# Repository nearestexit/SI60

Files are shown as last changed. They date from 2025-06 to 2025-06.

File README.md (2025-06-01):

# SI60

[QMK](https://github.com/qmk/qmk_firmware) Compatible Open Hardware GH60-compatible USB-C PCBs designed for use with [Hi-Tek 725 "Space Invaders" Switches](https://wiki.vintkeys.ca/NMB/Switches) in a variety of layouts, including variants of NMB keyboards with and without stepped caps.

## Overview
The main features of this project are:
 - Support for nearly every possible 60% set of caps you could use, including all NMB RT101+ keyboards in ANSI and ISO, with stepped and unstepped caps, Erase-Eaze, and ADDS/Televideo ANSI layouts.
 - Future-proof STM32F072CBT6 MCU
 - Design optimized for hand-soldering, with no parts smaller than 0603, and an MCU that does not require an external crystal
 - Compatibility with the original GH60 footprint
 - Compatibility (theoretically) with the Bakeneko60 footprint
 
 **Important: The distance from the plate to PCB on Space Invaders switches is larger than that for MX switches. You must do your own research to confirm compatibility with whatever case you choose.
 Tray-mount cases are likely to work okay, but for top-mount keyboards, the pins may short out on the bottom of the case.
 I will update this page when compatibility with a certain case is confirmed, but other than that, I cannot answer questions like "is X keyboard with this PCB"**

Production files are included for production at [JLCPCB](https://jlcpcb.com/).

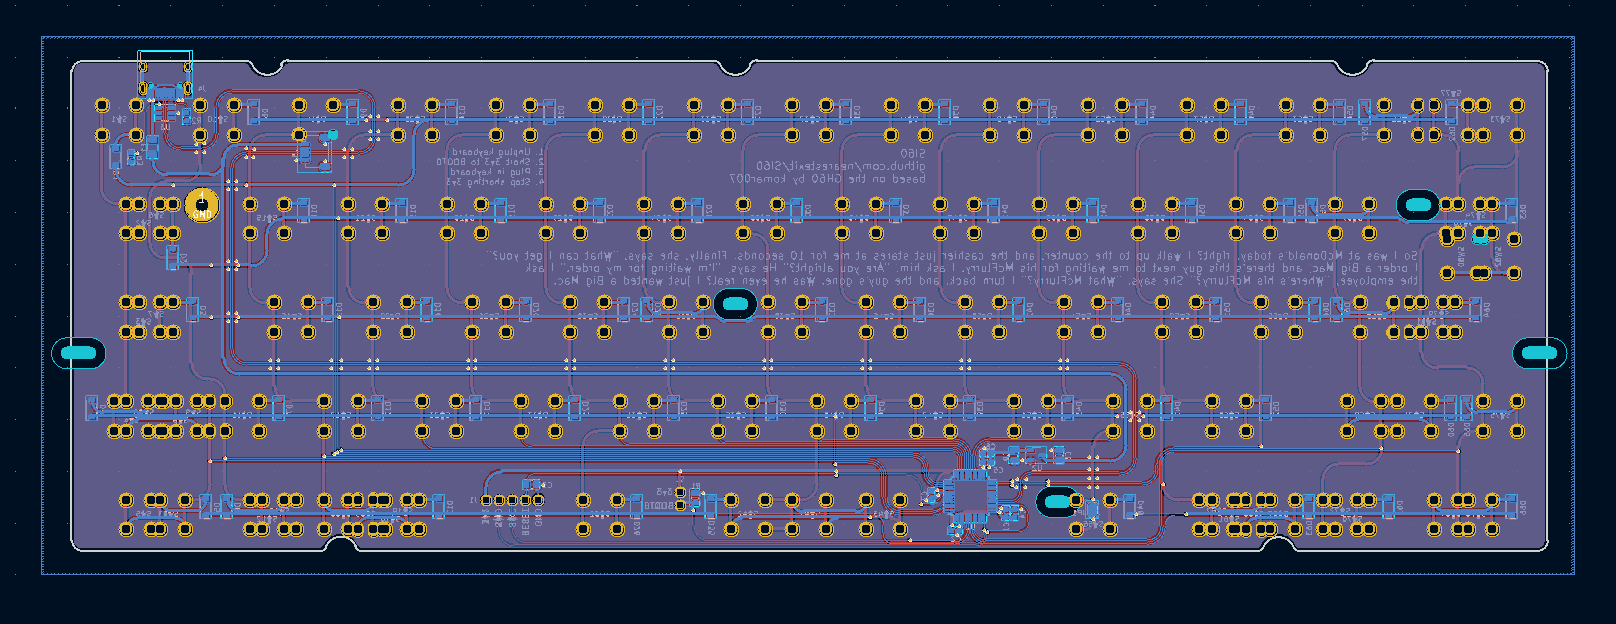
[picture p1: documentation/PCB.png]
Overview


## Supported layouts
 - Stepped and unstepped ISO, ANSI, BAE
 - Televideo ANSI bottom row
 - ADDS ANSI bottom row

**Please note: compatibility for the more obscure layouts is untested.**

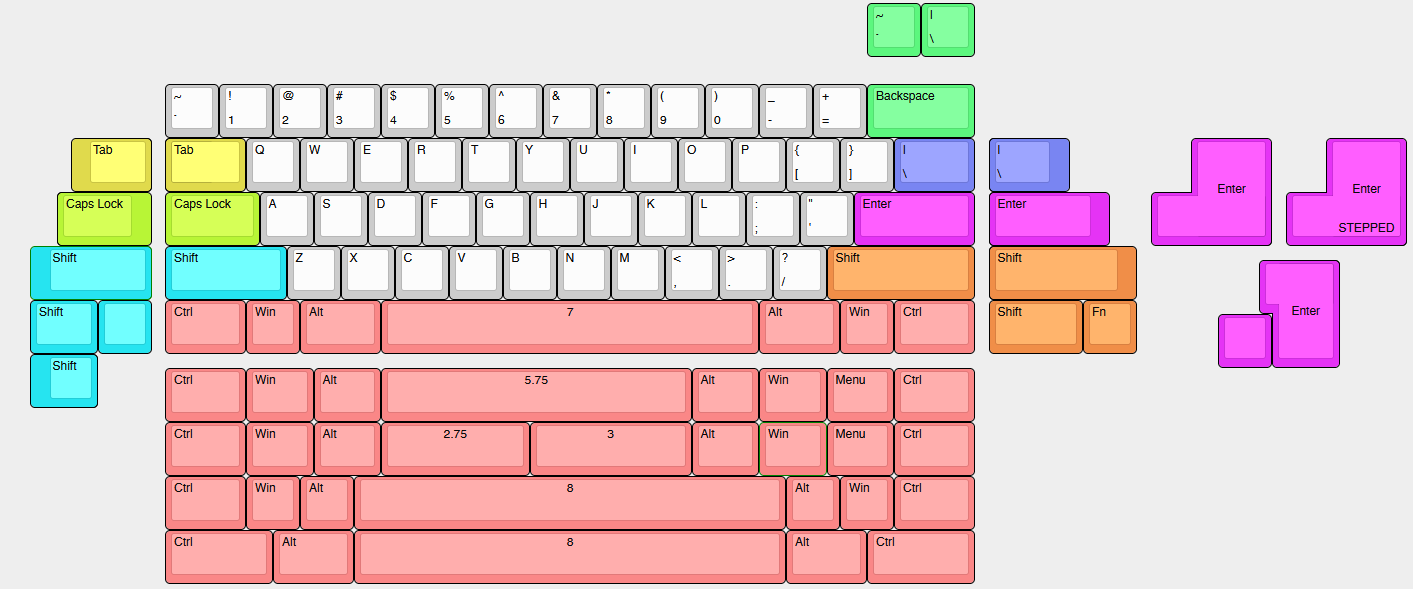
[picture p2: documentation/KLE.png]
KLE


## Configuration options
 - To fit in a GH60 case, the JST ought to be depopulated.
 - To fit in a Bakeneko60 case, the USB-C ought to be depopulated.

## JLCPCB Ordering Information
1. On jlcpcb.com, click "order now" and "add gerber file"
2. Navigate to the directory with the gerber.zip - for example, SI60\jlcpcb\production_files
3. Wait for the gerber to upload.
4. Select the number of PCBs you wish to build.
5. Make sure PCB thickness is set to 1.6mm.
6. Make sure Via covering is set to "tented".
7. Make sure Min via hole size/diameter is set to "0.3mm"
8. Turn the "PCB Assembly" option on
9. Make sure PCBA type is set to "Economic"
10. For "Assembly side", if you are ordering the daughterboard select "top side", otherwise select "bottom side"
11. Click "next", and then "next" again
12. Click "Add BOM File" and select the BOM csv - for example, BOM-SI60.csv
13. Click "Add CPL File" and select the CPL csv - for example, CPL-SI60.csv
14. Click "Process BOM and CPL"
15. Make sure all parts are in stock - if any are not in stock, you will need to find replacements
16. Decide whether you want the USB-C soldered or the JST soldered, and uncheck the box next to the one you don't want
17. **IMPORTANT:** Click "Bottom" to view the bottom side of the PCB, and begin inspecting the component placements. You **WILL** need to correct some component rotations. If you are not sure at this step, do not continue!
18. Click "next" and finish checking out.

## Firmware
- [Vial-QMK](https://get.vial.today/) .uf2 files are provided in the firmware folder.
- To put the keyboard into bootloader mode to flash the firmware:
1. Open QMK toolbox, select the firmware file, and check the box for "auto flash"
2. Unplug the USB cable
3. Short the 3v3 and BOOT0 pins with a pair of tweezers
4. Plug the USB cable in
5. Stop shorting the BOOT pins.
- The STM32 will then be recognized by QMK toolbox, and it will load the firmware.
- You may need to reconnect the keyboard after flashing.
- Once you have flashed the firmware, you can change the keymap from [vial.rocks](https://vial.rocks)

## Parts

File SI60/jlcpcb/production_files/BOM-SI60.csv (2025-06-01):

Comment | Designator | Footprint | LCSC | Quantity
100n | C1,C2,C5,C7 | C_0603_1608Metric | C14663 | 4
Conn_01x04_MountingPin | J3 | JST_SH_SM04B-SRSS-TB_1x04-1MP_P1.00mm_Horizontal | C160404 | 1
USB_C_Receptacle_USB2.0 | J4 | USB_C_Receptacle_HRO_TYPE-C-31-M-12 | C165948 | 1
10k | R1 | R_0805_2012Metric | C17414 | 1
4.7u | C4,C6 | C_0603_1608Metric | C19666 | 2
5.1k | R2,R3 | R_0603_1608Metric | C23186 | 2
1u | C3,C8,C9 | C_0805_2012Metric | C28323 | 3
XC6206PxxxMR | U2 | SOT-23-3 | C5446 | 1
500mA | F1 | Fuse_1206_3216Metric | C70076 | 1
D_Small | D1,D10,D11,D12,D13,D14,D15,D16,D17,D18,D19,D2,D20,D21,D22,D23,D24,D25,D26,D27,D28,D29,D3,D30,D31,D32,D33,D34,D35,D36,D37,D38,D39,D4,D40,D41,D42,D43,D44,D45,D46,D47,D48,D49,D5,D50,D51,D52,D53,D54,D55,D56,D57,D58,D59,D6,D60,D61,D62,D63,D64,D65,D66,D7,D8,D9 | D_SOD-123 | C81598 | 66
STM32F072CBTx | U1 | LQFP-48_7x7mm_P0.5mm | C81720 | 1
SRV05-4 | U3 | SOT-23-6-routable | C85364 | 1

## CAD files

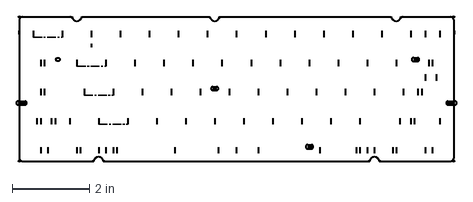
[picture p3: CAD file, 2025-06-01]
SI60/drawings/Drawing - PCB Layout.dxf
11.4 x 3.76 in

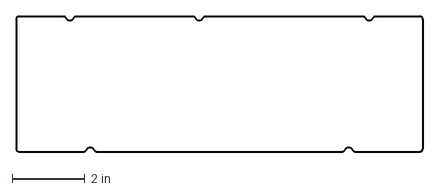
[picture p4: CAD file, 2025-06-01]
SI60/drawings/Drawing - PCB Edge Cuts.dxf
11.2 x 3.72 in

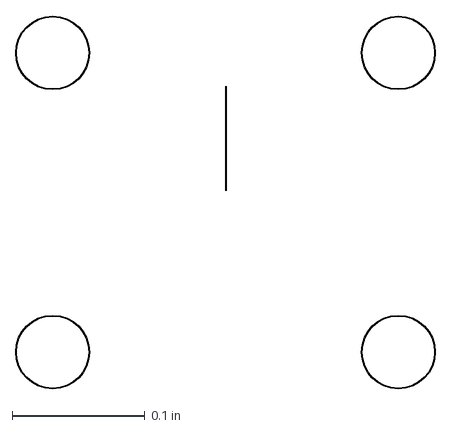
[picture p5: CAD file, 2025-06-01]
SI60/drawings/Footprint.dxf
0.315 x 0.28 in

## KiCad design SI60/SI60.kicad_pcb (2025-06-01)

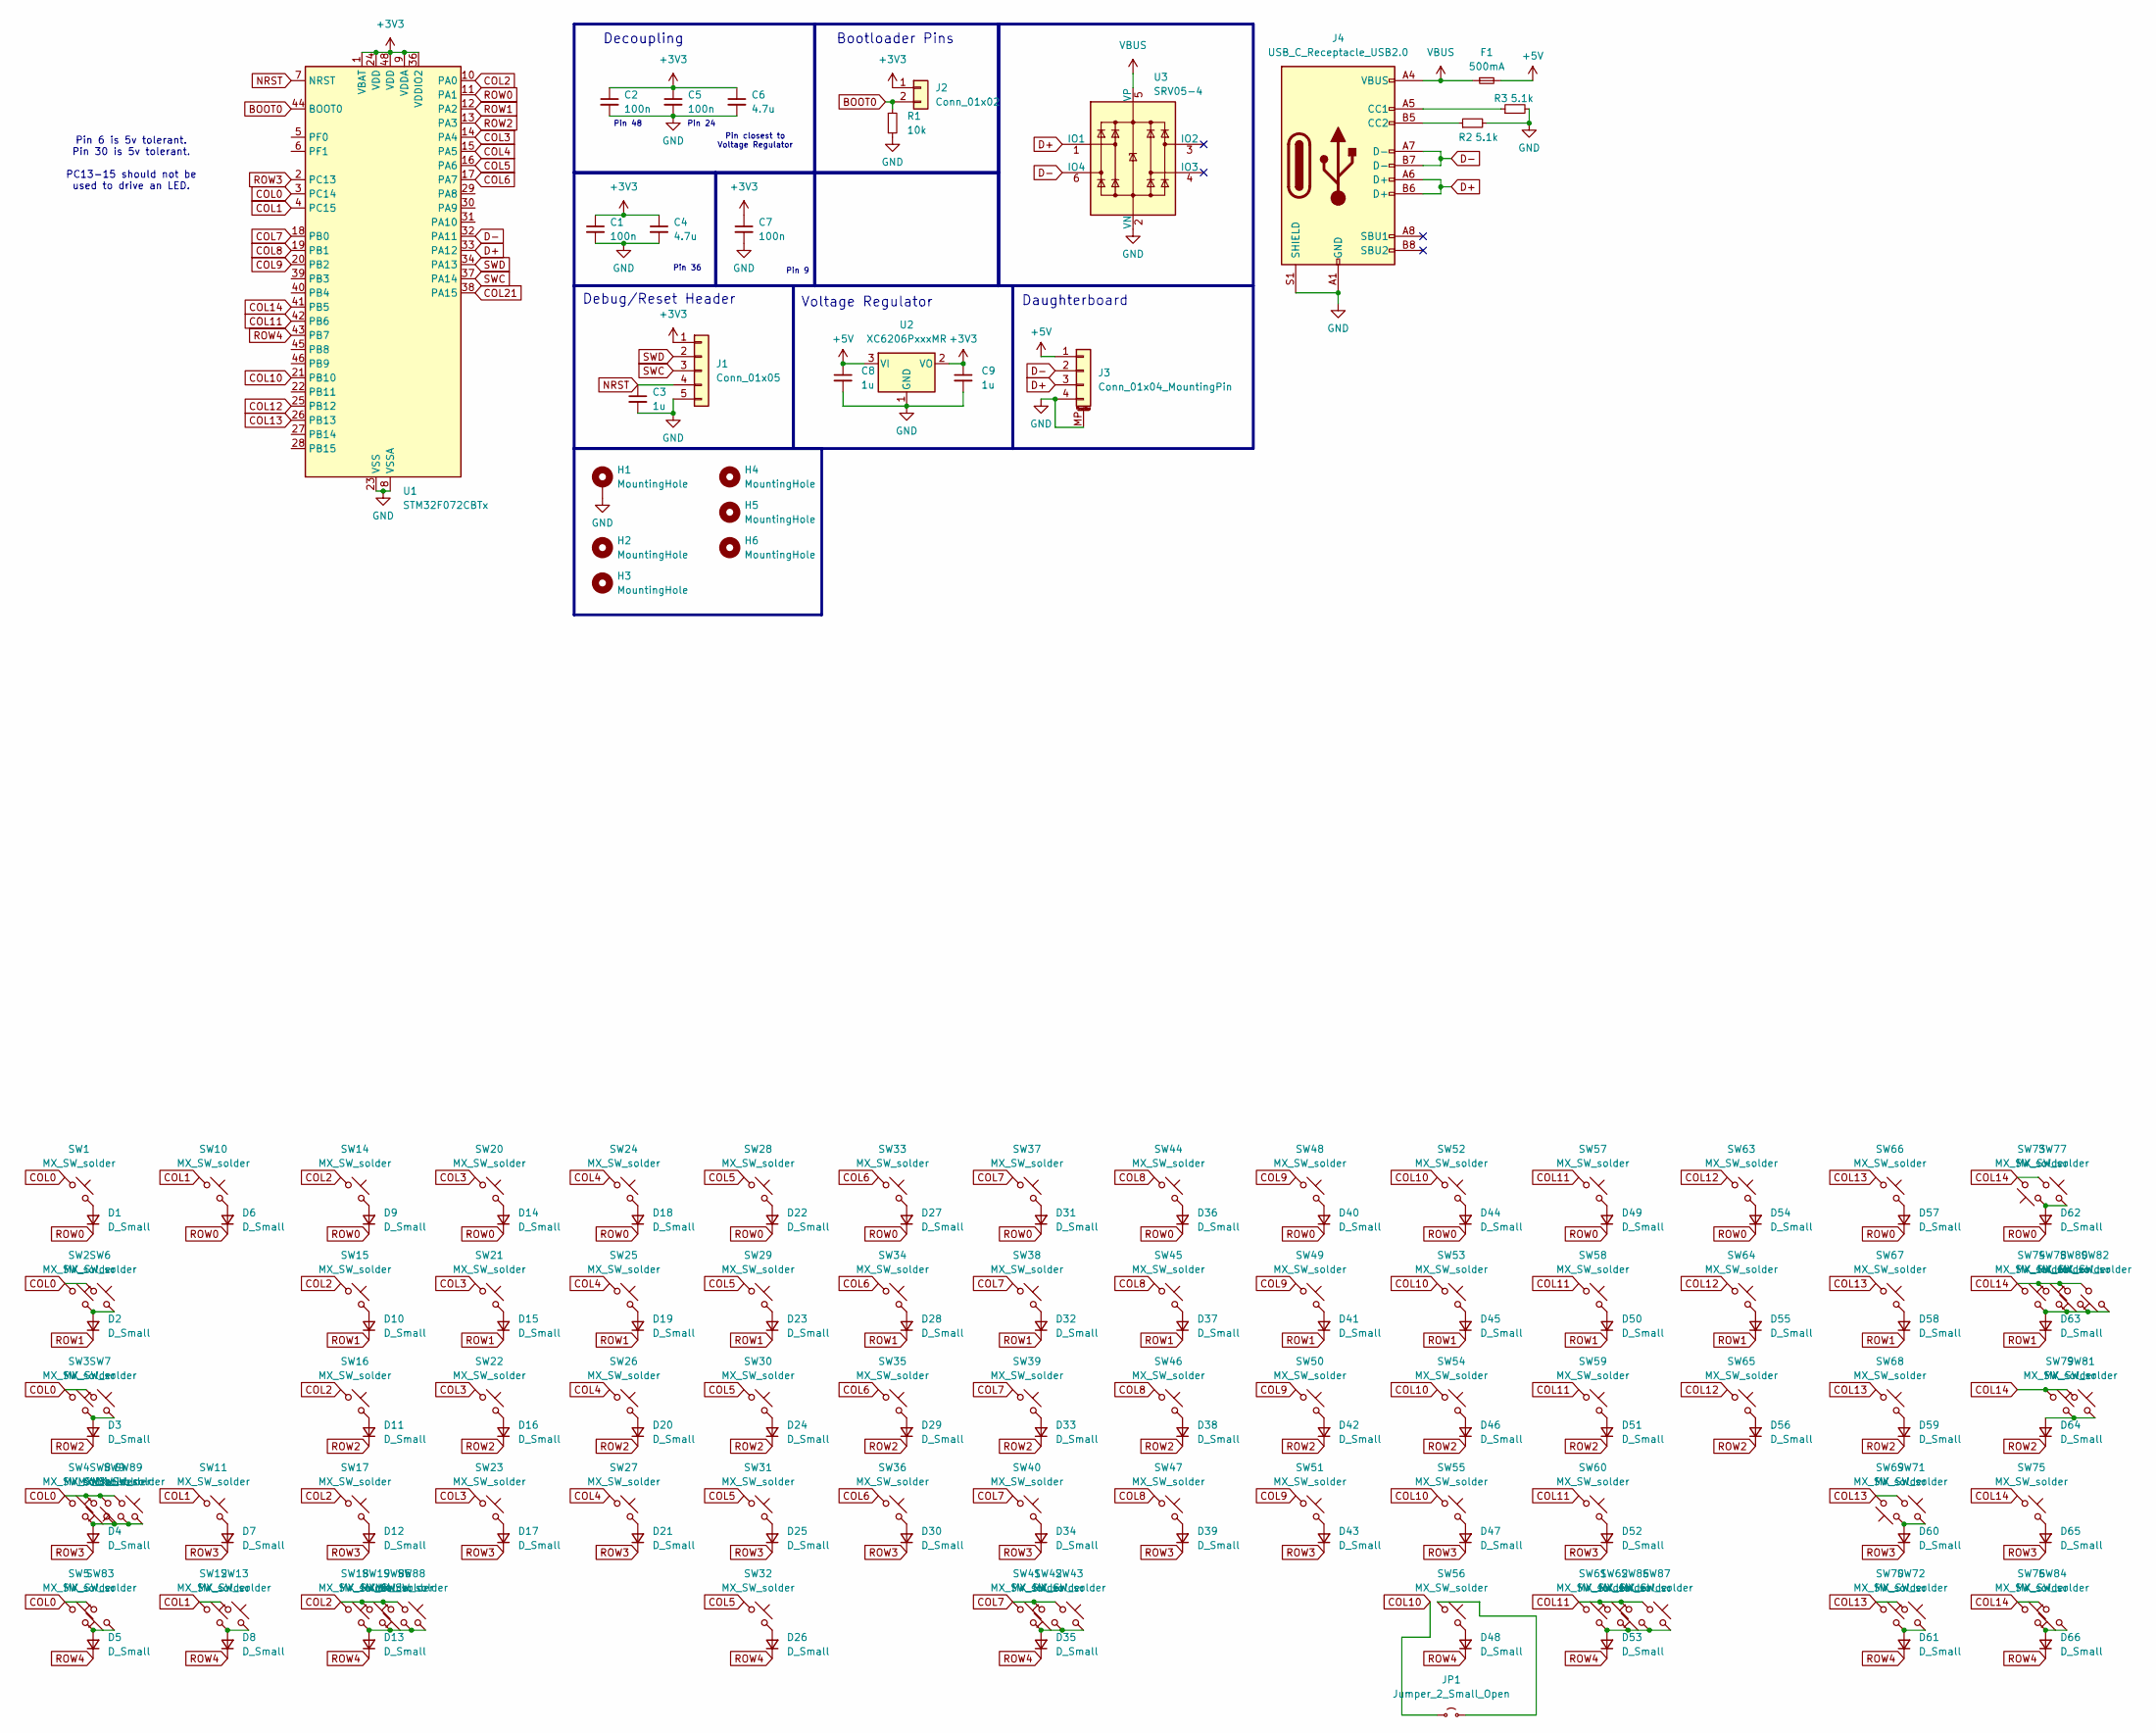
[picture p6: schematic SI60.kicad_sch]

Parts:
C1, C2, C5, C7: 100n; C_0603_1608Metric
C3, C8, C9: 1u; C_0805_2012Metric
C4, C6: 4.7u; C_0603_1608Metric
D1, D2, D3, D4, D5, D6, D7, D8, D9, D10, D11, D12, D13, D14, D15, D16, D17, D18, D19, D20, D21, D22, D23, D24, D25, D26, D27, D28, D29, D30, D31, D32, D33, D34, D35, D36, D37, D38, D39, D40, D41, D42, D43, D44, D45, D46, D47, D48, D49, D50, D51, D52, D53, D54, D55, D56, D57, D58, D59, D60, D61, D62, D63, D64, D65, D66: D_Small; D_SOD-123
F1: 500mA; Fuse_1206_3216Metric
H1: MountingHole; GH60_Standoff_Hole
H2, H3, H4: MountingHole; GH60_Standoff_Slot
H5, H6: MountingHole; GH60_Standoff_Slot_Edge
J1: Conn_01x05; PinHeader_1x05_P2.54mm_DEBUG
J2: Conn_01x02; PinHeader_1x02_P2.54mm_BOOT
J3: Conn_01x04_MountingPin; JST_SH_SM04B-SRSS-TB_1x04-1MP_P1.00mm_Horizontal
J4: USB_C_Receptacle_USB2.0; USB_C_Receptacle_HRO_TYPE-C-31-M-12
JP1: Jumper_2_Small_Open; SolderJumper-2_P1.3mm_Open_RoundedPad1.0x1.5mm
R1: 10k; R_0805_2012Metric
R2, R3: 5.1k; R_0603_1608Metric
SW1, SW2, SW3, SW4, SW5, SW6, SW7, SW8, SW10, SW12, SW13, SW15, SW16, SW17, SW19, SW20, SW21, SW22, SW23, SW24, SW25, SW26, SW27, SW28, SW29, SW30, SW31, SW32, SW33, SW34, SW35, SW36, SW37, SW38, SW39, SW40, SW41, SW42, SW43, SW44, SW45, SW46, SW47, SW48, SW49, SW50, SW51, SW52, SW53, SW54, SW55, SW56, SW57, SW58, SW59, SW60, SW62, SW63, SW64, SW65, SW67, SW69, SW70, SW71, SW72, SW73, SW74, SW75, SW76, SW78, SW79, SW83, SW84, SW85, SW86, SW89: MX_SW_solder; SW_HiTek725_1u
SW9, SW61, SW66, SW68, SW88: MX_SW_solder; SW_HiTek725_1u_OvalRight
SW11, SW18, SW77, SW81, SW87: MX_SW_solder; SW_HiTek725_1u_OvalLeft
SW14: MX_SW_solder; SW_HiTek725_1u_JST
SW80: MX_SW_solder; SW_HiTek725_BAE
SW82: MX_SW_solder; SW_HiTek725_ISO
U1: STM32F072CBTx; LQFP-48_7x7mm_P0.5mm
U2: XC6206PxxxMR; SOT-23-3
U3: SRV05-4; SOT-23-6-routable

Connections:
+3V3: C1.1, C2.1, C4.1, C5.1, C6.1, C7.1, C9.1, J1.1, J2.1, U1.1 (VBAT), U1.9 (VDDA), U1.24 (VDD), U1.36 (VDDIO2), U1.48 (VDD), U2.2 (VO)
+5V: C8.1, F1.2, J3.1, U2.3 (VI)
BOOT0: J2.2, R1.1, U1.44 (BOOT0)
COL0: SW1.1, SW2.1, SW3.1, SW4.1, SW5.1, SW6.1, SW7.1, SW8.2, SW9.2, SW83.2, SW89.1, U1.3 (PC14)
COL1: SW10.1, SW11.1, SW12.1, SW13.1, U1.4 (PC15)
COL2: SW14.1, SW15.1, SW16.1, SW17.1, SW18.1, SW19.1, SW85.2, SW88.1, U1.10 (PA0)
COL3: SW20.1, SW21.1, SW22.1, SW23.1, U1.14 (PA4)
COL4: SW24.1, SW25.1, SW26.1, SW27.1, U1.15 (PA5)
COL5: SW28.1, SW29.1, SW30.1, SW31.1, SW32.1, U1.16 (PA6)
COL6: SW33.1, SW34.1, SW35.1, SW36.1, U1.17 (PA7)
COL7: SW37.1, SW38.1, SW39.1, SW40.1, SW41.1, SW42.2, SW43.1, U1.18 (PB0)
COL8: SW44.1, SW45.1, SW46.1, SW47.1, U1.19 (PB1)
COL9: SW48.1, SW49.1, SW50.1, SW51.1, U1.20 (PB2)
COL10: JP1.1 (A), SW52.1, SW53.1, SW54.1, SW55.1, U1.21 (PB10)
COL11: SW57.1, SW58.1, SW59.1, SW60.1, SW61.1, SW62.1, SW86.2, SW87.1, U1.42 (PB6)
COL12: SW63.1, SW64.1, SW65.1, U1.25 (PB12)
COL13: SW66.1, SW67.1, SW68.1, SW69.2, SW70.1, SW71.1, SW72.1, U1.26 (PB13)
COL14: SW73.2, SW74.1, SW75.1, SW76.1, SW77.1, SW78.1, SW79.1, SW80.2, SW81.1, SW82.2, SW84.2, U1.41 (PB5)
COL21: U1.38 (PA15)
D+: J3.3, J4.A6 (D+), J4.B6 (D+), U1.33 (PA12), U3.1 (IO1)
D-: J3.2, J4.A7 (D-), J4.B7 (D-), U1.32 (PA11), U3.6 (IO4)
GND: C1.2, C2.2, C3.2, C4.2, C5.2, C6.2, C7.2, C8.2, C9.2, H1.1, J1.5, J3.4, J3.MP (MountPin), J4.A1 (GND), J4.A12 (GND), J4.B1 (GND), J4.B12 (GND), J4.S1 (SHIELD), R1.2, R2.2, R3.2, U1.8 (VSSA), U1.23 (VSS), U1.35 (VSS), U1.47 (VSS), U2.1 (GND), U3.2 (VN)
NRST: C3.1, J1.4, U1.7 (NRST)
unnamed: D1.2 (A), SW1.2
unnamed: D2.2 (A), SW2.2, SW6.2
unnamed: D3.2 (A), SW3.2, SW7.2
unnamed: D4.2 (A), SW4.2, SW8.1, SW9.1, SW89.2
unnamed: D5.2 (A), SW5.2, SW83.1
unnamed: D6.2 (A), SW10.2
unnamed: D7.2 (A), SW11.2
unnamed: D8.2 (A), SW12.2, SW13.2
unnamed: D9.2 (A), SW14.2
unnamed: D10.2 (A), SW15.2
unnamed: D11.2 (A), SW16.2
unnamed: D12.2 (A), SW17.2
unnamed: D13.2 (A), SW18.2, SW19.2, SW85.1, SW88.2
unnamed: D14.2 (A), SW20.2
unnamed: D15.2 (A), SW21.2
unnamed: D16.2 (A), SW22.2
unnamed: D17.2 (A), SW23.2
unnamed: D18.2 (A), SW24.2
unnamed: D19.2 (A), SW25.2
unnamed: D20.2 (A), SW26.2
unnamed: D21.2 (A), SW27.2
unnamed: D22.2 (A), SW28.2
unnamed: D23.2 (A), SW29.2
unnamed: D24.2 (A), SW30.2
unnamed: D25.2 (A), SW31.2
unnamed: D26.2 (A), SW32.2
unnamed: D27.2 (A), SW33.2
unnamed: D28.2 (A), SW34.2
unnamed: D29.2 (A), SW35.2
unnamed: D30.2 (A), SW36.2
unnamed: D31.2 (A), SW37.2
unnamed: D32.2 (A), SW38.2
unnamed: D33.2 (A), SW39.2
unnamed: D34.2 (A), SW40.2
unnamed: D35.2 (A), SW41.2, SW42.1, SW43.2
unnamed: D36.2 (A), SW44.2
unnamed: D37.2 (A), SW45.2
unnamed: D38.2 (A), SW46.2
unnamed: D39.2 (A), SW47.2
unnamed: D40.2 (A), SW48.2
unnamed: D41.2 (A), SW49.2
unnamed: D42.2 (A), SW50.2
unnamed: D43.2 (A), SW51.2
unnamed: D44.2 (A), SW52.2
unnamed: D45.2 (A), SW53.2
unnamed: D46.2 (A), SW54.2
unnamed: D47.2 (A), SW55.2
unnamed: D48.2 (A), SW56.2
unnamed: D49.2 (A), SW57.2
unnamed: D50.2 (A), SW58.2
unnamed: D51.2 (A), SW59.2
unnamed: D52.2 (A), SW60.2
unnamed: D53.2 (A), SW61.2, SW62.2, SW86.1, SW87.2
unnamed: D54.2 (A), SW63.2
unnamed: D55.2 (A), SW64.2
unnamed: D56.2 (A), SW65.2
unnamed: D57.2 (A), SW66.2
unnamed: D58.2 (A), SW67.2
unnamed: D59.2 (A), SW68.2
unnamed: D60.2 (A), SW69.1, SW71.2
unnamed: D61.2 (A), SW70.2, SW72.2
unnamed: D62.2 (A), SW73.1, SW77.2
unnamed: D63.2 (A), SW74.2, SW78.2, SW80.1, SW82.1
unnamed: D64.2 (A), SW79.2, SW81.2
unnamed: D65.2 (A), SW75.2
unnamed: D66.2 (A), SW76.2, SW84.1
unnamed: J4.A5 (CC1), R3.1
unnamed: J4.B5 (CC2), R2.1
unnamed: JP1.2 (B), SW56.1
ROW0: D1.1 (K), D6.1 (K), D9.1 (K), D14.1 (K), D18.1 (K), D22.1 (K), D27.1 (K), D31.1 (K), D36.1 (K), D40.1 (K), D44.1 (K), D49.1 (K), D54.1 (K), D57.1 (K), D62.1 (K), U1.11 (PA1)
ROW1: D2.1 (K), D10.1 (K), D15.1 (K), D19.1 (K), D23.1 (K), D28.1 (K), D32.1 (K), D37.1 (K), D41.1 (K), D45.1 (K), D50.1 (K), D55.1 (K), D58.1 (K), D63.1 (K), U1.12 (PA2)
ROW2: D3.1 (K), D11.1 (K), D16.1 (K), D20.1 (K), D24.1 (K), D29.1 (K), D33.1 (K), D38.1 (K), D42.1 (K), D46.1 (K), D51.1 (K), D56.1 (K), D59.1 (K), D64.1 (K), U1.13 (PA3)
ROW3: D4.1 (K), D7.1 (K), D12.1 (K), D17.1 (K), D21.1 (K), D25.1 (K), D30.1 (K), D34.1 (K), D39.1 (K), D43.1 (K), D47.1 (K), D52.1 (K), D60.1 (K), D65.1 (K), U1.2 (PC13)
ROW4: D5.1 (K), D8.1 (K), D13.1 (K), D26.1 (K), D35.1 (K), D48.1 (K), D53.1 (K), D61.1 (K), D66.1 (K), U1.43 (PB7)
SWC: J1.3, U1.37 (PA14)
SWD: J1.2, U1.34 (PA13)
VBUS: F1.1, J4.A4 (VBUS), J4.A9 (VBUS), J4.B4 (VBUS), J4.B9 (VBUS), U3.5 (VP)

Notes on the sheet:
Pin closest to Voltage Regulator
Pin 6 is 5v tolerant. Pin 30 is 5v tolerant. PC13-15 should not be used to drive an LED.
Debug/Reset Header
Daughterboard
Pin 48
Pin 36
Pin 24
Pin 9
Decoupling
Bootloader Pins
Voltage Regulator

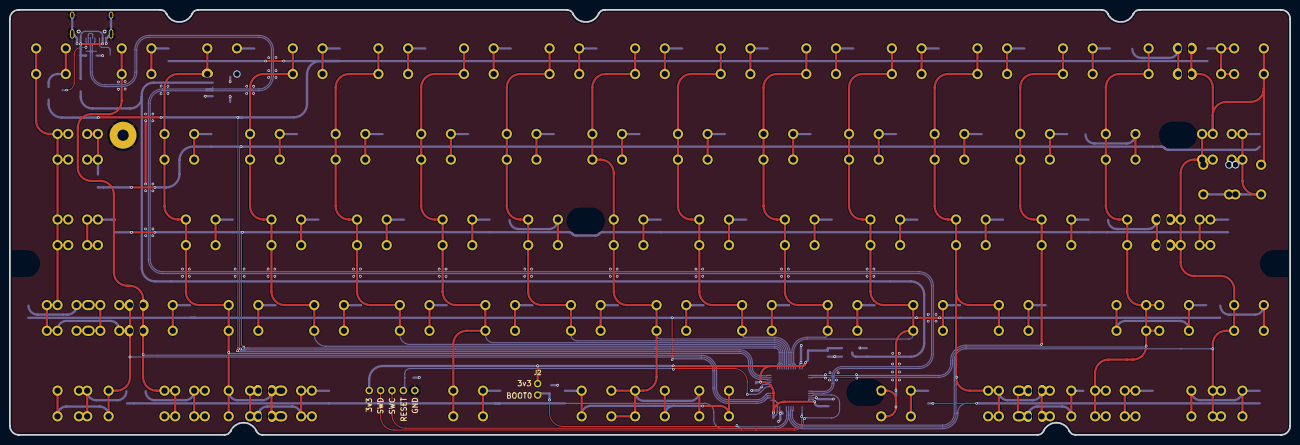
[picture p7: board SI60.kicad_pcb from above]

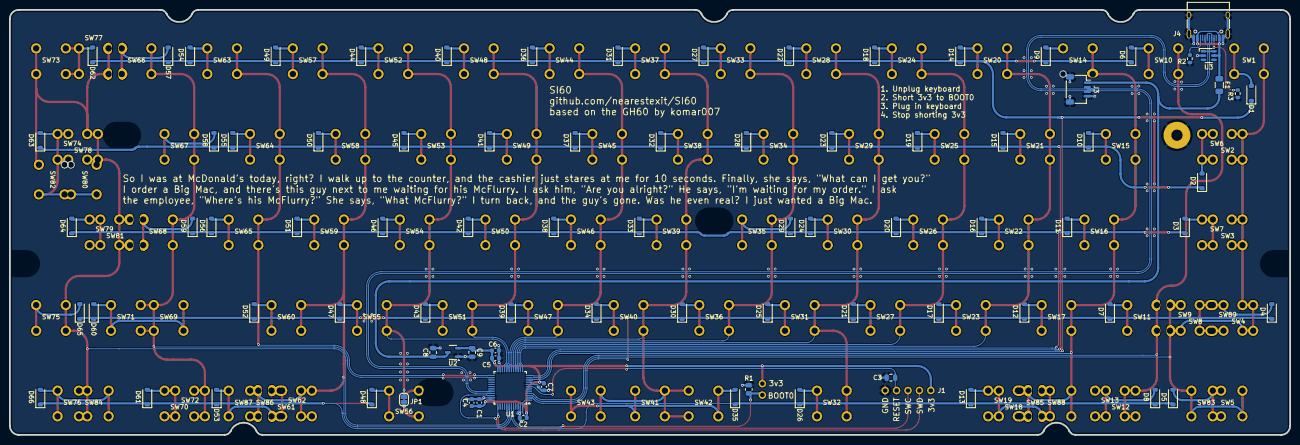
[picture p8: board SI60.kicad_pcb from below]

Board: 2 copper layers, 285.0 x 94.6 mm, 182 parts (85 on the bottom side), 99 nets.
